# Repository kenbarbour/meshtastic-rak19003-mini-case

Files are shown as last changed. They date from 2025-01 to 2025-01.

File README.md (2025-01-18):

# Meshtastic RAK19003 Mini Case

A case for the RAK19003.  The dimensions of this case are adjustable to fit
various components inside.

__WARNING__: This is a work in progress.  The design is not yet complete.

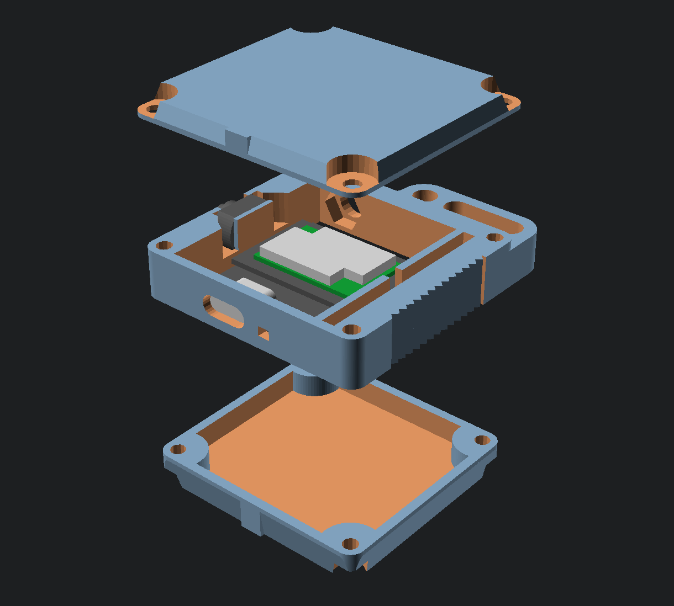
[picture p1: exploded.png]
exploded view


## Printable Parts:

* Frame
* Front Cover
* Back Cover

## Hardware:
* WisBlock RAK19003 Starter Kit
* 4x M3x20 socket head cap screws
* 4x M3 Hex nuts
* 1 LiPo Battery with JST-PH connector (500-1200 mAh)
* 1 BK-1208 Pushbutton

## Printing Instructions
1. Run `make models` to generate models in the `models/` directory.
2. Generate gcode for the STL models with your favorite slicer.
3. Print a frame, top, and bottom, of either size.

## License
This project is licensed under the [Creative Commons Attribution 4.0 International (CC BY 4.0)](https://creativecommons.org/licenses/by/4.0/) license. You are free to share and adapt the design as long as proper attribution is given.

### Attribution
If you use or adapt this design, please credit Ken Barbour and include a reference to this repository.

## Support my work

If you would like to support my work, please consider making a
[donation](https://www.paypal.com/donate/?hosted_button_id=HPYB829J25LYC).

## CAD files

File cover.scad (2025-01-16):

use <lib/utils.scad>;

module case_cover(
	length=47,
	width=50,
	thickness=4,
	hex=false,
	counterboreDepth=3,
	counterboreDiameter=8) {

	bottomThickness = 1;
	topThickness = 2;
	mountHoleOffset = 3; // must match the value in case_frame
	mountHoleSize = 3;
	draftOffset = 1;
	wallThickness = 2;
	e = 0.1; // small waste number; not for final geometry

	assert(thickness >= (counterboreDepth+bottomThickness), "case_cover thickness is too small");

	difference() {
		union() {
			cube([
				length,
				width,
				bottomThickness
			]);
			translate([0, 0, bottomThickness])
				truncated_pyramid(length=length, width=width, height=thickness-bottomThickness, inset=draftOffset);

			// Feet - for stability
			footWidth = 5;
			translate([0, (width - footWidth)/2, 0])
				cube([ length/2, footWidth, thickness]);

		}

		for (position = mounting_bolts(length, width, mountHoleOffset)) {
			translate([position[0], position[1], 0-e]) {
				clearance_hole(mountHoleSize);
				translate([0,0, thickness - counterboreDepth])
				if (hex) {
					cylinder(r=counterboreDiameter/2 * (sqrt(3)/2), h=counterboreDepth+e+e, $fn=6);
				} else {
					clearance_hole(counterboreDiameter, counterboreDepth+e);
				}
			}
		}
		// Corner Radiuses
		translate([0, 0, 0-e])          rotate([0, 0, 0])    z_fillet(3);
		translate([length, 0, 0-e])     rotate([0, 0, 90])   z_fillet(3);
		translate([0, width, 0-e])      rotate([0, 0, 270])  z_fillet(3);
		translate([length, width, 0-e]) rotate([0, 0, 180])  z_fillet(3);

		// Inner cavity
		difference() {
			translate([
				wallThickness,
				wallThickness,
				0-e
			])
			cube([
				length - 2*wallThickness,
				width - 2*wallThickness,
				thickness - topThickness + e
			]);

			for (position = mounting_bolts(length, width, mountHoleOffset)) {
				translate([position[0], position[1], 0-e]) {
					innerCavityRadius = max((counterboreDiameter/2)+topThickness,wallThickness);
					cylinder(r=innerCavityRadius, h=thickness-topThickness+e+e);
				}
			}
		}
	}

}

module truncated_pyramid(length, width, height, inset=5) {
	polyhedron(
		points=[
			[0      , 0     , 0]      , // 0
			[length , 0     , 0]      , // 1
			[length , width , 0]      , // 2
			[0      , width , 0]      , // 3

			[inset        , inset       , height] , // 4
			[length-inset , inset       , height] , // 5
			[length-inset , width-inset , height] , // 6
			[inset        , width-inset , height] , // 7
		],
		faces=[
			[1, 0, 4],
			[4, 5, 1],
			[2, 1, 5],
			[5, 6, 2],
			[3, 2, 6],
			[6, 7, 3],
			[0, 3, 7],
			[7, 4, 0],
			[7, 6, 5],
			[4, 7, 5],
			[0, 1, 3],
			[1, 2, 3],
		],
		convexity=1
	);
}

case_cover($fn=32);

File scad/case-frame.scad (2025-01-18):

use <lib/rak19003.scad>;
use <lib/utils.scad>;
use <lib/switch.scad>;

module case_frame(
	length=47,      // x-length; excludes lanyard loop
	width=50,       // y-width
	thickness=10    // z-height; overall height of this part
) {
	/*
	 * TODO: refactor this so that the width and length are configurable
	 * directly, and the bolt pattern is purely functional
	 */
	flange = 1.25; // Thickness of the mounting flange for board
	wallThickness = [5, 5.5, 2, 7.5]; // 0:top, 1:right, 2:bottom, 3:left
	boardOffset = [.2, 1, 0.25];
	mountHoleOffset = 3;
	mountHoleSize = 3.2;
	e = 0.1; // small number for rounding errors, should NOT affect geometry
	lanyardWidth = min(8, thickness);

	// TODO: add BLE antenna
	bleAntClearance = 2.6; // clearance for the thickness of the BLE antenna
	bleWall = 1.6;
	bleWidth = bleWall + bleAntClearance;

	cavityLength = length - wallThickness[2] - wallThickness[0];
	cavityWidth = width - wallThickness[1] - wallThickness[3] - bleWidth;


	// DESIGN CHECK: ensure that the inner cavity is large enough
	minCavityLength = 40;
	minCavityWidth = 32;
	assert(cavityLength >= minCavityLength, "case-frame inner cavity is not long enough");
	assert(cavityWidth >= minCavityWidth, "case-frame inner cavity is not wide enough");

	
	difference() {
		union() {
			round_rect([length, width, thickness], r=3);
			translate([
				length, 0, 0
			])
			lanyard_loop(
				width=lanyardWidth,
				length=width-20,
				overflow=length/2, // large enough to overcome the corner fillet
				slotDiameter=6
			);
		}

		// Remove main cavity
		difference() {
			translate([
				wallThickness[2],
				wallThickness[1],
				0-e
			]) cube([
				cavityLength,
				cavityWidth + bleWidth,
				thickness+2*e
				]);

			// board mount - offset to match board
			translate([
				wallThickness[2] + boardOffset[0],
				wallThickness[1] + boardOffset[1] + bleWidth,
				0
			])
				board_mount(thickness=flange, zOffset=boardOffset[2]);

			// BLE Mount
			bleMaxLength = 44;
			translate([
				wallThickness[2],
				wallThickness[1],
				0
			]) ble_mount(
				height=thickness,
				length=min(bleMaxLength, cavityLength),
				wall=bleWall,
				clearance=bleAntClearance);
		}

		// Case cover mounting holes
		for ( position = mounting_bolts(length, width, mountHoleOffset)) {
			translate([position[0], position[1], 0])
			clearance_hole(mountHoleSize);
		}

		// antenna mount
		translate([
			length-wallThickness[0] - e,
			width-wallThickness[3] - 6,
			thickness/2
		])
		rotate([90, 0, 0])
		rotate([0, 90, 0])
			antenna_mount();
		// clearance for antenna
		antennaClearanceRadius = 7; // space for wide antenna bases
		translate([
			length,
			width-wallThickness[3] - 6,
			thickness/2
		])
		rotate([0, 90, 0])
			cylinder(r=antennaClearanceRadius, h=100);

		// usb port
		translate([
			0-e,
			boardOffset[1] + wallThickness[1] + bleWidth + 14 - 0.5,
			flange + boardOffset[2] + 1.1 - 0.5,
		])
			usb_c(width=10, h=4.25, $fn=24);

		// reset button hole
		// TODO: enlarge and move reset button hole
		translate([
			0-e,
			boardOffset[1] + wallThickness[1] + bleWidth + 9,
			flange + boardOffset[2] + 1.1,
		])
			cube([wallThickness[2]+e+e, 2.5, 2]);

		// led holes
		for (yOffset = [1, 5, 27]) {
			translate([
				0-e,
				boardOffset[1] + wallThickness[1] + bleWidth + yOffset +0.5,
				flange + boardOffset[2] + 1.1,
			])
			cube([
				wallThickness[2]+e+e,
				1,
				1
			]);
		}

		// pushbutton mount
		// TODO: make pushbutton mount stronger
		translate([
			length/2,
			width-5.5,
			thickness-4
		])
		rotate([-90, 0, 0])
		pushbutton_mount();

		// side texture/grip
		gripLength = length - 20;
		translate([
			(length-gripLength)/2,
			0,
			0
		])
		grip_texture(gripLength, 1, thickness+e);

	}

	// Show board for reference only
	translate([
		wallThickness[2] + boardOffset[0],
		wallThickness[1] + boardOffset[1] + bleWidth,
		flange + boardOffset[2]
		])
	%rak19003_model();
	
}

module board_mount(thickness=1.2, zOffset=1, overflow=[10,10]) {
	e = 0.1;
	difference() {
		union() {
			translate([0-overflow[0], 0-overflow[1], 0])
			cube([
				7 + overflow[0],
				30 + overflow[1],
				thickness,
			]);
			rak19003_mounting_holes(diameter=4, h=(thickness + zOffset),
			includePartial=false, $fn=16);
		}

		// mount holes - interference for self threading
		translate([0,0,0-e]) {
		rak19003_mounting_holes(diameter=2.5, $fn=16);
		}

		// clearance for large components
		translate([ 2, 7, 0-e ])
			cube([ 10, 15, thickness+2*e ]);
	}
	// simple tab to help stabilize the board
	translate([ 10.5, 0-overflow[1], 0-e ])
		cube([ 5, 2+overflow[1], thickness+2*e ]);
}

module antenna_mount(hex_depth=3) {
	hexagonal_prism(d_flat=8.1, h=hex_depth);
	clearance_hole(6.3, e=0.1);
}

module ble_mount(length=45, height=10, wall=1.6, clearance=2.6,) {
	e = 0.01;
	antWidth = 7.2;
	antLength = 41;

	assert(height > antWidth, "BLE patch antenna is taller than height (z)");
	assert(length >= antLength, "BLE patch antenna is longer than length (x)");

	difference() {
		cube([
			length,
			wall+clearance,
			height
		]);

		// slot for patch antenna
		translate([ 0, 0-e, height - antWidth])
		cube([
			antLength,
			clearance+e,
			antWidth + e
		]);

		// slot for feed line (centered)
		feedLine = 3.5;
		translate([ (antLength-feedLine)/2, clearance-e, 0-e])
			cube([
				feedLine,
				wall + e + e,
				height + e + e
			]);
	}

}

module pushbutton_mount(clearance=0.3) {
	thru = 20; // large number to go through the other geometry
	// button clearance
	cylinder(r=5/2, h=thru, $fn=16);

	// slot to drop in button
	translate([(12+(2*clearance))/-2, 0-thru, 0])
	cube([12 + (2*clearance), thru, 4.3]);
	translate([(6.9+(2*clearance))/-2, 0-thru, 0])
	cube([6.9 + (2*clearance), thru, 6.3]);

	pushbutton_bk1208(clearance=clearance);

	difference() {
		translate([0, 2.5-thru, -8])
		rotate([-90, 0, 0])
		cylinder(r=13, h=thru);

		// leave a tab to hold the button
		translate([-5, 5-thru, 0-thru])
		cube([10, thru, thru]);
	}
	// render button for reference only
	%pushbutton_bk1208();
}

case_frame($fn=32);

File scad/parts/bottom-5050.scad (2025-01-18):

use <../cover.scad>;

width             = 50;
length            = 50;
topThickness      = 2;
batteryThickness  = 7;
thickness         = topThickness+batteryThickness;
fastenerThickness = 2.6; // thickness at the fasteners

case_cover(
	length=length,
	width=width,
	thickness=thickness,
	topThickness=topThickness,
	hex=true,
	counterboreDepth=(thickness-fastenerThickness),
	counterboreDiameter=6.5,  // wrench size of an M3 + clearance
	$fn=32
);

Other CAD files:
scad/cover.scad
scad/parts/bottom-5060.scad
scad/parts/frame-5050.scad
scad/parts/frame-5060.scad
scad/parts/top-5050.scad
scad/parts/top-5060.scad

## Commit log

2025-01-13 Housekeeping
    - README is a markdown
    - added lib dir for utilities not meant to generate models
    - added Makefile to generate models and gcode
    [case-frame.scad]
2025-01-13 Case-frame is defined by its outer dimensions
    To make it easy to design the frame to fit the covers, it is defined by
    its length, width, and thickness. There are checks to ensure that the
    inner cavity is large enough to fit the RAK19003 module.
    [case-frame.scad]
2025-01-13 Added Bluetooth Patch Antenna mount
    [case-frame.scad]
2025-01-13 Add a power toggle switch
    [case-frame.scad]
2025-01-14 Added a hole for reset button access
    [case-frame.scad]
2025-01-14 added a cover
    This handles both top and bottom
    [cover.scad]
2025-01-15 Added texture, lanyard loop, and feet for cover
    [case-frame.scad, cover.scad]
2025-01-15 fix BLE antenna dimensions
    [case-frame.scad]
2025-01-15 added some TODOs to fix after the first test print
    [case-frame.scad]
2025-01-15 stronger button mount
    [case-frame.scad]
2025-01-15 make the lanyard loop larger
    [case-frame.scad]
2025-01-15 Put back original size for antenna hex
    This size holds the antenna firmly
    [case-frame.scad]
2025-01-16 more public parameters of cover
    [cover.scad]
2025-01-17 reorganization
    Parts for printing are in their own directory
    Added help to makefile to build each part
    [bottom-5060.scad, case-frame.scad, cover.scad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]
2025-01-17 Changes after some test prints:
    - more clearance for antenna mount
    - more width for BLE antenna
    - slightly larger screw holes for interference board mount
    - moved reset button hole
    - added led holes
    [case-frame.scad, top-5060.scad]
2025-01-17 add more space in top for cable clearance
    [top-5060.scad]
2025-01-17 bottom cover corner fixes
    - remove small bits of corner material left after the captive hex
    [bottom-5060.scad, cover.scad]
2025-01-17 oops, fixed BLE mount
    actually adjusted the correct dimension this time
    [case-frame.scad]
2025-01-18 Some edits while fitting components together
    - bottom cover fitment for battery
    - cover thickness
    [bottom-5060.scad, cover.scad, top-5060.scad]
2025-01-18 larger case mounting holes for clearance
    [case-frame.scad, cover.scad]
2025-01-18 add charging LED
    [case-frame.scad]
2025-01-18 updates with assembly instructions
    [bottom-5050.scad, frame-5050.scad, top-5050.scad]
